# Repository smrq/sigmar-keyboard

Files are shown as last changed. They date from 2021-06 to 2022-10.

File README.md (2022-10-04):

# Sigmar Keyboard

40% split keyboard design



## PCB

The design for the PCB was done in KiCad. The PCB is designed according to the specifications of manufacturing with [JLCPCB](https://jlcpcb.com/).

## Firmware

Prerequisites:

* Podman
* dfu-programmer

Building:

* `make docker` to build the container image
* `make` to build the bootloader and firmware hex files

Flashing:

* `make flash left` or `make flash right`

### Building and flashing in WSL

* Install Ubuntu >= 22.04
* Install usbipd-win
* `sudo apt install dfu-programmer podman`

Flashing:

* In Powershell
	- `usbipd list`
		- Find the entry that corresponds with the keyboard (when in keyboard mode, VID/PID is f055:5164)
	- Press the reset button to switch to flashing mode
		- You will need another keyboard or the on-screen virtual keyboard from now on! If the latter, it might help to type the following commands beforehand, so you only need to press enter.
	- `usbipd wsl attach --busid=#-##`

* In WSL
	- `make flash-left` or `make flash-right`

### Flashing the bootloader with Arduino ISP

* Connect Arduino ISP
	* MOSI Pin 11 (programmer) -> B2 (target)
	* MISO Pin 12 -> B3
	* SCK Pin 13 -> B1
	* RST Pin 10 -> RST
* `make build/sigmar_[osx|windows]_bootloader.hex`
* `avrdude -p atmega32u4 -F -P COM4 -c stk500v1 -b 19200 -U flash:w:build/sigmar_[osx|windows]_bootloader.hex`
	* `-P COM4` should match the serial port for the Arduino ISP

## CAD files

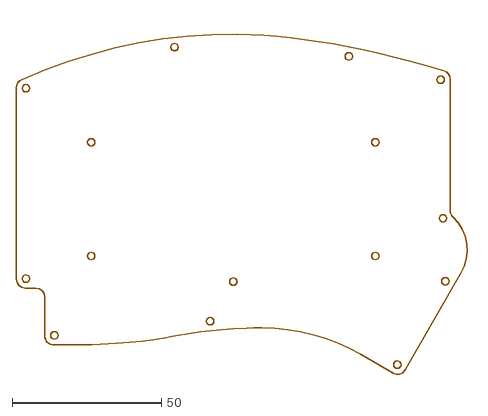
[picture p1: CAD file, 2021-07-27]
model/svg/01-back.dxf
152.5 x 120.4

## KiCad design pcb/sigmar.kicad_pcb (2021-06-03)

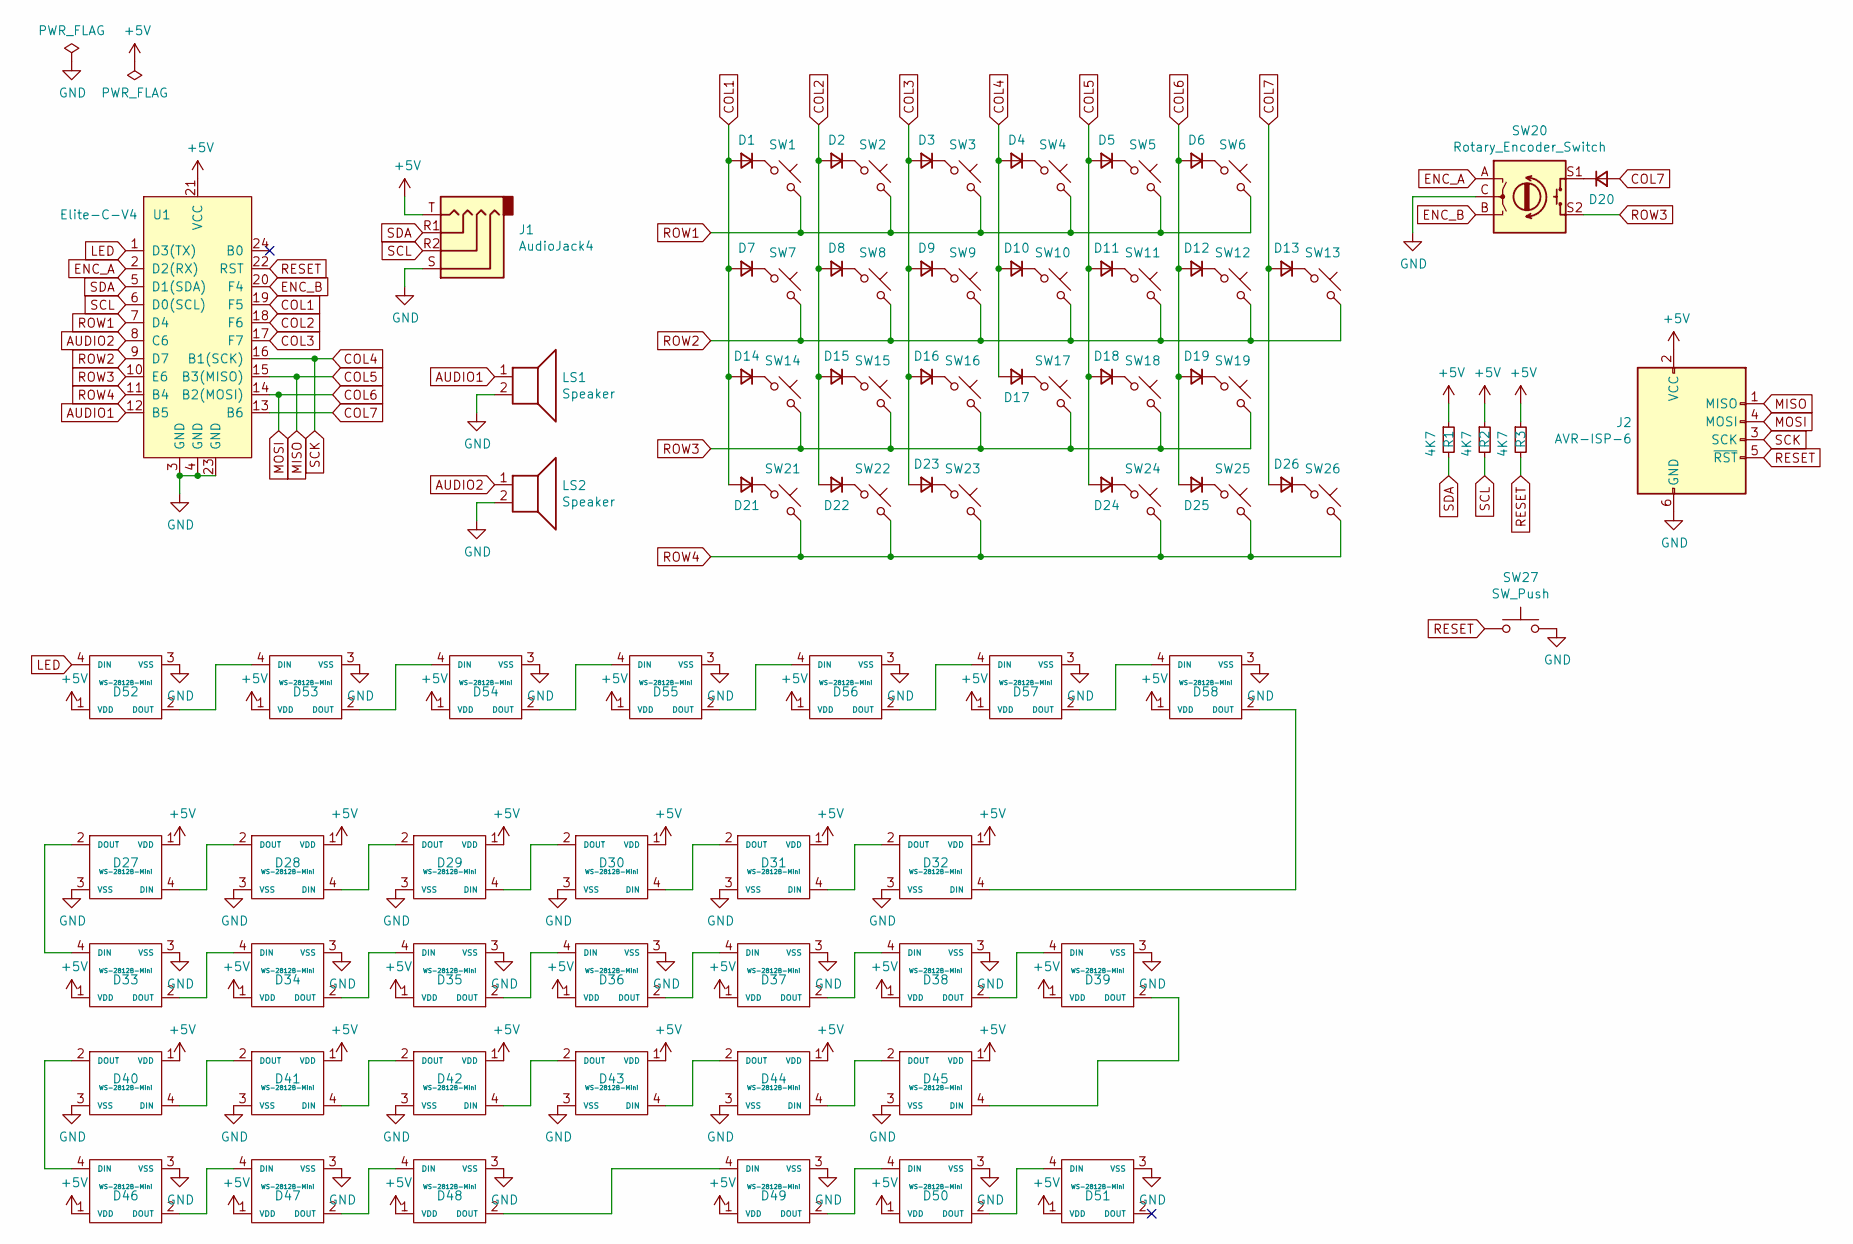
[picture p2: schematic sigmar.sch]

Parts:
D1, D2, D3, D4, D5, D6, D7, D8, D9, D10, D11, D12, D13, D14, D15, D16, D17, D18, D19, D20, D21, D22, D23, D24, D25, D26: D_Small; D_MiniMELF
D27, D28, D29, D30, D31, D32, D33, D34, D35, D36, D37, D38, D39, D40, D41, D42, D43, D44, D45, D46, D47, D48, D49, D50, D51: WS-2812B-Mini; LED_3535_Through_Reversible
D52, D53, D54, D55, D56, D57, D58: WS-2812B-Mini; LED_3535_Reversible
J1: AudioJack4; TRRS-PJ-320A_Reversible
J2: AVR-ISP-6; AVR-ISP
LS1, LS2: Speaker; KLJ-1102_Reversible
R1, R2, R3: 4K7; R_0805
SW1, SW2, SW3, SW4, SW5, SW6, SW7, SW8, SW9, SW10, SW11, SW12, SW14, SW15, SW16, SW17, SW18, SW19, SW21, SW22, SW23, SW24, SW25, SW26: SW_Push_45deg; Cherry_MX_1U_Reversible
SW13: SW_Push_45deg; Cherry_MX_2U_Vert_Reversible
SW20: Rotary_Encoder_Switch; RotaryEncoder_EC11_Reversible
SW27: SW_Push; SPST_MJTP1117_Reversible
U1: Elite-C-V4; Elite-C

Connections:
+5V: D27.1 (VDD), D28.1 (VDD), D29.1 (VDD), D30.1 (VDD), D31.1 (VDD), D32.1 (VDD), D33.1 (VDD), D34.1 (VDD), D35.1 (VDD), D36.1 (VDD), D37.1 (VDD), D38.1 (VDD), D39.1 (VDD), D40.1 (VDD), D41.1 (VDD), D42.1 (VDD), D43.1 (VDD), D44.1 (VDD), D45.1 (VDD), D46.1 (VDD), D47.1 (VDD), D48.1 (VDD), D49.1 (VDD), D50.1 (VDD), D51.1 (VDD), D52.1 (VDD), D53.1 (VDD), D54.1 (VDD), D55.1 (VDD), D56.1 (VDD), D57.1 (VDD), D58.1 (VDD), J1.T, J2.2 (VCC), R1.1, R2.1, R3.1, U1.21 (VCC)
AUDIO1: LS1.1, U1.12 (B5)
AUDIO2: LS2.1, U1.8 (C6)
COL1: D1.2 (A), D7.2 (A), D14.2 (A), D21.2 (A), U1.19 (F5)
COL2: D2.2 (A), D8.2 (A), D15.2 (A), D22.2 (A), U1.18 (F6)
COL3: D3.2 (A), D9.2 (A), D16.2 (A), D23.2 (A), U1.17 (F7)
COL4: D4.2 (A), D10.2 (A), D17.2 (A), J2.3 (SCK), U1.16 (B1(SCK))
COL5: D5.2 (A), D11.2 (A), D18.2 (A), D24.2 (A), J2.1 (MISO), U1.15 (B3(MISO))
COL6: D6.2 (A), D12.2 (A), D19.2 (A), D25.2 (A), J2.4 (MOSI), U1.14 (B2(MOSI))
COL7: D13.2 (A), D20.2 (A), D26.2 (A), U1.13 (B6)
ENC_A: SW20.A, U1.2 (D2(RX))
ENC_B: SW20.B, U1.20 (F4)
GND: D27.3 (VSS), D28.3 (VSS), D29.3 (VSS), D30.3 (VSS), D31.3 (VSS), D32.3 (VSS), D33.3 (VSS), D34.3 (VSS), D35.3 (VSS), D36.3 (VSS), D37.3 (VSS), D38.3 (VSS), D39.3 (VSS), D40.3 (VSS), D41.3 (VSS), D42.3 (VSS), D43.3 (VSS), D44.3 (VSS), D45.3 (VSS), D46.3 (VSS), D47.3 (VSS), D48.3 (VSS), D49.3 (VSS), D50.3 (VSS), D51.3 (VSS), D52.3 (VSS), D53.3 (VSS), D54.3 (VSS), D55.3 (VSS), D56.3 (VSS), D57.3 (VSS), D58.3 (VSS), J1.S, J2.6 (GND), LS1.2, LS2.2, SW20.C, SW27.2, U1.3 (GND), U1.4 (GND), U1.23 (GND)
LED: D52.4 (DIN), U1.1 (D3(TX))
unnamed: D1.1 (K), SW1.1
unnamed: D2.1 (K), SW2.1
unnamed: D3.1 (K), SW3.1
unnamed: D4.1 (K), SW4.1
unnamed: D5.1 (K), SW5.1
unnamed: D6.1 (K), SW6.1
unnamed: D7.1 (K), SW7.1
unnamed: D8.1 (K), SW8.1
unnamed: D9.1 (K), SW9.1
unnamed: D10.1 (K), SW10.1
unnamed: D11.1 (K), SW11.1
unnamed: D12.1 (K), SW12.1
unnamed: D13.1 (K), SW13.1
unnamed: D14.1 (K), SW14.1
unnamed: D15.1 (K), SW15.1
unnamed: D16.1 (K), SW16.1
unnamed: D17.1 (K), SW17.1
unnamed: D18.1 (K), SW18.1
unnamed: D19.1 (K), SW19.1
unnamed: D20.1 (K), SW20.S1
unnamed: D21.1 (K), SW21.1
unnamed: D22.1 (K), SW22.1
unnamed: D23.1 (K), SW23.1
unnamed: D24.1 (K), SW24.1
unnamed: D25.1 (K), SW25.1
unnamed: D26.1 (K), SW26.1
unnamed: D27.2 (DOUT), D33.4 (DIN)
unnamed: D27.4 (DIN), D28.2 (DOUT)
unnamed: D28.4 (DIN), D29.2 (DOUT)
unnamed: D29.4 (DIN), D30.2 (DOUT)
unnamed: D30.4 (DIN), D31.2 (DOUT)
unnamed: D31.4 (DIN), D32.2 (DOUT)
unnamed: D32.4 (DIN), D58.2 (DOUT)
unnamed: D33.2 (DOUT), D34.4 (DIN)
unnamed: D34.2 (DOUT), D35.4 (DIN)
unnamed: D35.2 (DOUT), D36.4 (DIN)
unnamed: D36.2 (DOUT), D37.4 (DIN)
unnamed: D37.2 (DOUT), D38.4 (DIN)
unnamed: D38.2 (DOUT), D39.4 (DIN)
unnamed: D39.2 (DOUT), D45.4 (DIN)
unnamed: D40.2 (DOUT), D46.4 (DIN)
unnamed: D40.4 (DIN), D41.2 (DOUT)
unnamed: D41.4 (DIN), D42.2 (DOUT)
unnamed: D42.4 (DIN), D43.2 (DOUT)
unnamed: D43.4 (DIN), D44.2 (DOUT)
unnamed: D44.4 (DIN), D45.2 (DOUT)
unnamed: D46.2 (DOUT), D47.4 (DIN)
unnamed: D47.2 (DOUT), D48.4 (DIN)
unnamed: D48.2 (DOUT), D49.4 (DIN)
unnamed: D49.2 (DOUT), D50.4 (DIN)
unnamed: D50.2 (DOUT), D51.4 (DIN)
unnamed: D52.2 (DOUT), D53.4 (DIN)
unnamed: D53.2 (DOUT), D54.4 (DIN)
unnamed: D54.2 (DOUT), D55.4 (DIN)
unnamed: D55.2 (DOUT), D56.4 (DIN)
unnamed: D56.2 (DOUT), D57.4 (DIN)
unnamed: D57.2 (DOUT), D58.4 (DIN)
RESET: J2.5 (~RST), R3.2, SW27.1, U1.22 (RST)
ROW1: SW1.2, SW2.2, SW3.2, SW4.2, SW5.2, SW6.2, U1.7 (D4)
ROW2: SW7.2, SW8.2, SW9.2, SW10.2, SW11.2, SW12.2, SW13.2, U1.9 (D7)
ROW3: SW14.2, SW15.2, SW16.2, SW17.2, SW18.2, SW19.2, SW20.S2, U1.10 (E6)
ROW4: SW21.2, SW22.2, SW23.2, SW24.2, SW25.2, SW26.2, U1.11 (B4)
SCL: J1.R2, R2.2, U1.6 (D0(SCL))
SDA: J1.R1, R1.2, U1.5 (D1(SDA))

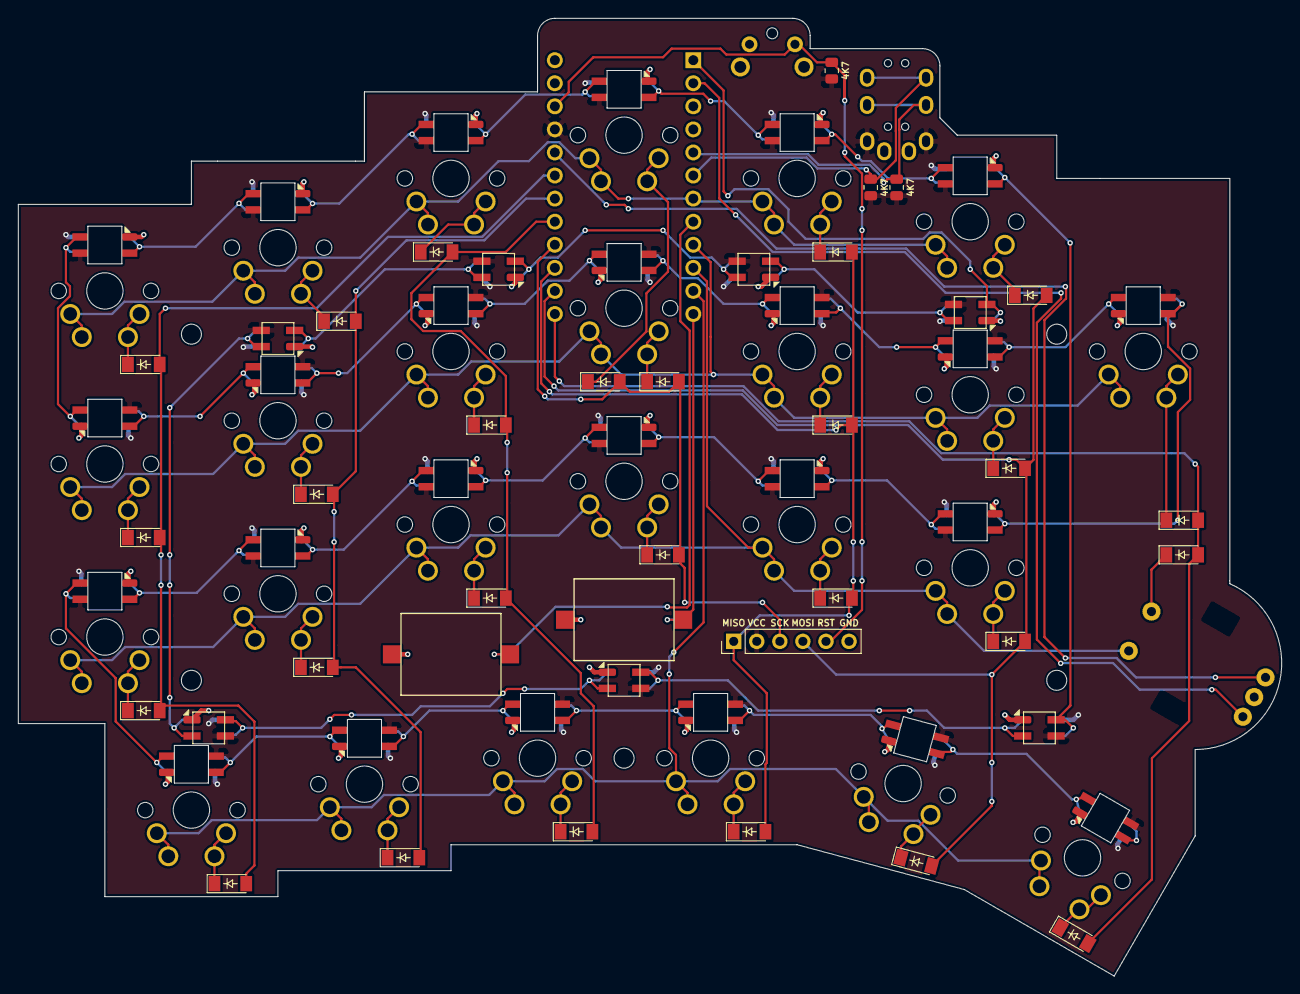
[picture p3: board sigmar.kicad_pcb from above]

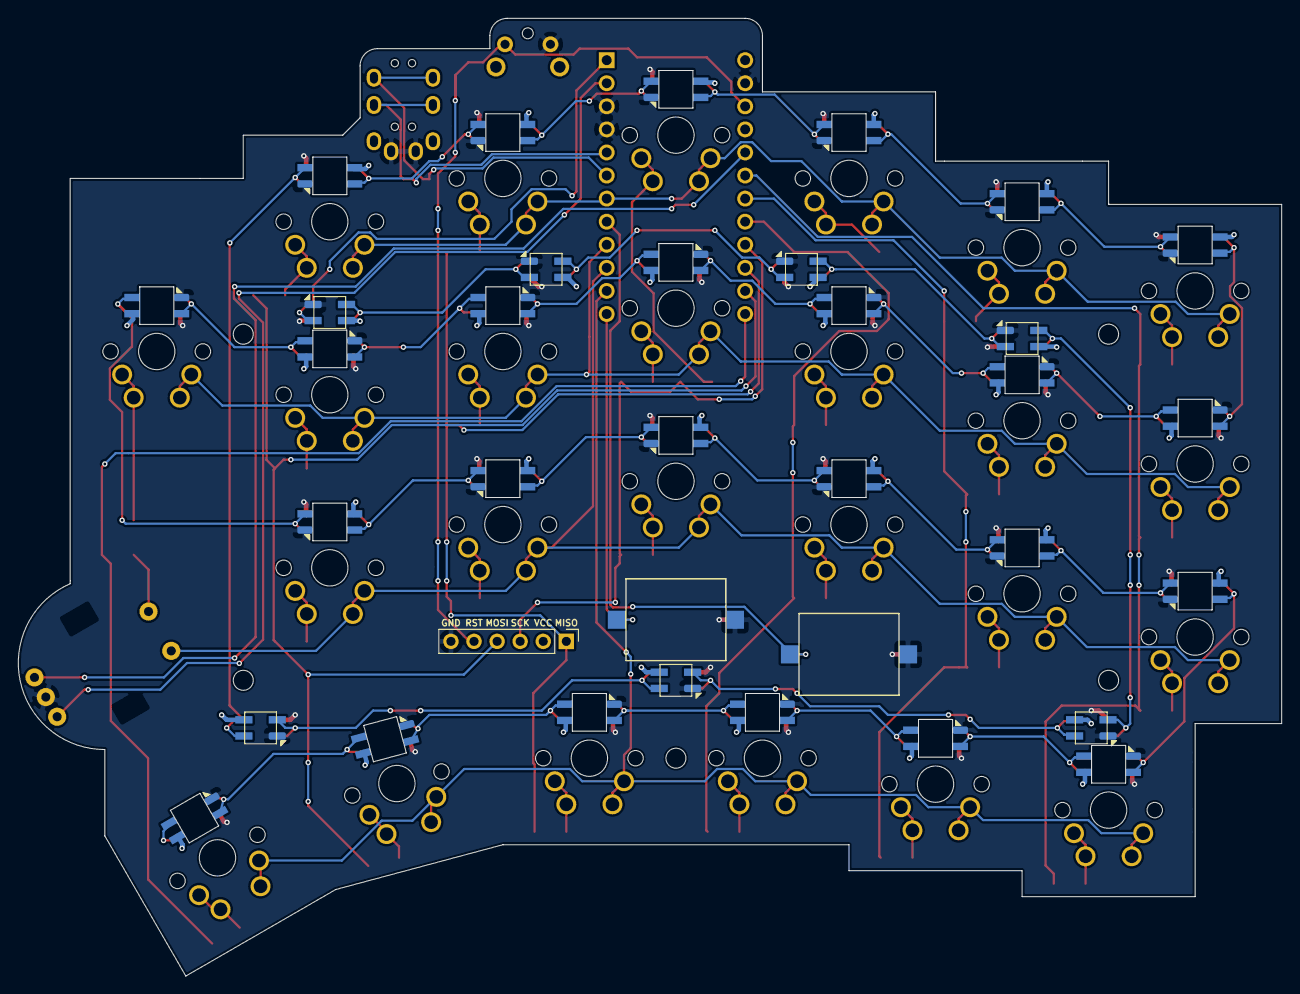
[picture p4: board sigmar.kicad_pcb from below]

Board: 2 copper layers, 139.1 x 105.4 mm, 93 parts (37 on the bottom side), 78 nets.

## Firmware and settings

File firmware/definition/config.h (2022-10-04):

#pragma once

#include "config_common.h"

// https://docs.qmk.fm/#/config_options?id=hardware-options
#define VENDOR_ID    0xF055
#define PRODUCT_ID   0x5164
#define DEVICE_VER   0x0002
#define MANUFACTURER smrq
#define PRODUCT      Sigmar Keyboard

#define MATRIX_ROWS 8
#define MATRIX_COLS 7
#define MATRIX_ROW_PINS { D4, D7, E6, B4 }
#define MATRIX_COL_PINS { F5, F6, F7, B1, B3, B2, B6 }
#define DIODE_DIRECTION COL2ROW

#define DEBOUNCE 5
#define LOCKING_SUPPORT_ENABLE
#define LOCKING_RESYNC_ENABLE

// https://docs.qmk.fm/#/feature_rgb_matrix?id=rgb-matrix-lighting

#ifdef RGB_MATRIX_ENABLE
	#define RGB_DI_PIN D3
	#define DRIVER_LED_TOTAL 64

	#define RGB_MATRIX_SPLIT { 32, 32 }
	// #define RGB_MATRIX_FRAMEBUFFER_EFFECTS
	#define RGB_MATRIX_KEYPRESSES
	#define RGB_MATRIX_MAXIMUM_BRIGHTNESS 120

	#define DISABLE_RGB_MATRIX_ALPHAS_MODS
	#define DISABLE_RGB_MATRIX_GRADIENT_UP_DOWN
	#define DISABLE_RGB_MATRIX_GRADIENT_LEFT_RIGHT
	#define DISABLE_RGB_MATRIX_BREATHING
	#define DISABLE_RGB_MATRIX_BAND_SAT
	#define DISABLE_RGB_MATRIX_BAND_VAL
	#define DISABLE_RGB_MATRIX_BAND_PINWHEEL_SAT
	#define DISABLE_RGB_MATRIX_BAND_PINWHEEL_VAL
	#define DISABLE_RGB_MATRIX_BAND_SPIRAL_SAT
	#define DISABLE_RGB_MATRIX_BAND_SPIRAL_VAL
	#define DISABLE_RGB_MATRIX_CYCLE_ALL
	#define DISABLE_RGB_MATRIX_CYCLE_LEFT_RIGHT
	#define DISABLE_RGB_MATRIX_CYCLE_UP_DOWN
	// #define DISABLE_RGB_MATRIX_RAINBOW_MOVING_CHEVRON
	#define DISABLE_RGB_MATRIX_CYCLE_OUT_IN
	#define DISABLE_RGB_MATRIX_CYCLE_OUT_IN_DUAL
	#define DISABLE_RGB_MATRIX_CYCLE_PINWHEEL
	#define DISABLE_RGB_MATRIX_CYCLE_SPIRAL
	#define DISABLE_RGB_MATRIX_DUAL_BEACON
	#define DISABLE_RGB_MATRIX_RAINBOW_BEACON
	#define DISABLE_RGB_MATRIX_RAINBOW_PINWHEELS
	#define DISABLE_RGB_MATRIX_RAINDROPS
	#define DISABLE_RGB_MATRIX_JELLYBEAN_RAINDROPS
	#define DISABLE_RGB_MATRIX_HUE_BREATHING
	#define DISABLE_RGB_MATRIX_HUE_PENDULUM
	// #define DISABLE_RGB_MATRIX_HUE_WAVE
	#define DISABLE_RGB_MATRIX_TYPING_HEATMAP
	#define DISABLE_RGB_MATRIX_DIGITAL_RAIN
	#define DISABLE_RGB_MATRIX_SOLID_REACTIVE_SIMPLE
	#define DISABLE_RGB_MATRIX_SOLID_REACTIVE
	#define DISABLE_RGB_MATRIX_SOLID_REACTIVE_WIDE
	// #define DISABLE_RGB_MATRIX_SOLID_REACTIVE_MULTIWIDE
	#define DISABLE_RGB_MATRIX_SOLID_REACTIVE_CROSS
	#define DISABLE_RGB_MATRIX_SOLID_REACTIVE_MULTICROSS
	#define DISABLE_RGB_MATRIX_SOLID_REACTIVE_NEXUS
	#define DISABLE_RGB_MATRIX_SOLID_REACTIVE_MULTINEXUS
	#define DISABLE_RGB_MATRIX_SPLASH
	// #define DISABLE_RGB_MATRIX_MULTISPLASH
	#define DISABLE_RGB_MATRIX_SOLID_SPLASH
	// #define DISABLE_RGB_MATRIX_SOLID_MULTISPLASH
#endif

// https://docs.qmk.fm/#/feature_audio?id=audio
#ifdef AUDIO_ENABLE
	#define SND_ONE_UP_SOUND \
	    Q__NOTE(_E6),    \
	    Q__NOTE(_G6),    \
	    Q__NOTE(_E7),    \
	    Q__NOTE(_C7),    \
	    Q__NOTE(_D7),    \
	    Q__NOTE(_G7),

	#define SND_ZELDA_PUZZLE \
	    Q__NOTE(_G5),    \
	    Q__NOTE(_FS5),   \
	    Q__NOTE(_DS5),   \
	    Q__NOTE(_A4),    \
	    Q__NOTE(_GS4),   \
	    Q__NOTE(_E5),    \
	    Q__NOTE(_GS5),   \
	    HD_NOTE(_C6),

	#define SND_MARIO_MUSHROOM \
	    S__NOTE(_C5 ), \
	    S__NOTE(_G4 ), \
	    S__NOTE(_C5 ), \
	    S__NOTE(_E5 ), \
	    S__NOTE(_G5 ), \
	    S__NOTE(_C6 ), \
	    S__NOTE(_G5 ), \
	    S__NOTE(_GS4), \
	    S__NOTE(_C5 ), \
	    S__NOTE(_DS5), \
	    S__NOTE(_GS5), \
	    S__NOTE(_DS5), \
	    S__NOTE(_GS5), \
	    S__NOTE(_C6 ), \
	    S__NOTE(_DS6), \
	    S__NOTE(_GS6), \
	    S__NOTE(_DS6), \
	    S__NOTE(_AS4), \
	    S__NOTE(_D5 ), \
	    S__NOTE(_F5 ), \
	    S__NOTE(_AS5), \
	    S__NOTE(_D6 ), \
	    S__NOTE(_F6 ), \
	    S__NOTE(_AS6), \
	    S__NOTE(_F6 )

	#define SND_RICK_ROLL      \
	    Q__NOTE(_F4),      \
	    Q__NOTE(_G4),      \
	    Q__NOTE(_BF4),     \
	    Q__NOTE(_G4),      \
	    HD_NOTE(_D5),      \
	    HD_NOTE(_D5),      \
	    W__NOTE(_C5),      \
	    S__NOTE(_REST),    \
	    Q__NOTE(_F4),      \
	    Q__NOTE(_G4),      \
	    Q__NOTE(_BF4),     \
	    Q__NOTE(_G4),      \
	    HD_NOTE(_C5),      \
	    HD_NOTE(_C5),      \
	    W__NOTE(_BF4),     \
	    S__NOTE(_REST),    \
	    Q__NOTE(_F4),      \
	    Q__NOTE(_G4),      \
	    Q__NOTE(_BF4),     \
	    Q__NOTE(_G4),      \
	    W__NOTE(_BF4),     \
	    H__NOTE(_C5),      \
	    H__NOTE(_A4),      \
	    H__NOTE(_A4),      \
	    H__NOTE(_G4),      \
	    H__NOTE(_F4),      \
	    H__NOTE(_F4),      \
	    W__NOTE(_C5),      \
	    W__NOTE(_BF4),

	#define AUDIO_PIN C6
	#define AUDIO_PIN_ALT B5

	#define UNICODE_SONG_MAC  SONG(TERMINAL_SOUND)
	#define UNICODE_SONG_LNX  SONG(UNICODE_LINUX)
	#define UNICODE_SONG_WIN  SONG(UNICODE_WINDOWS)
	#define UNICODE_SONG_WINC SONG(UNICODE_WINDOWS)

	#define NO_MUSIC_MODE
#endif

// https://docs.qmk.fm/#/feature_split_keyboard?id=split-keyboard
#define EE_HANDS
// #define USE_I2C
#define USE_SERIAL
#define SOFT_SERIAL_PIN D0
#define SPLIT_TRANSPORT_MIRROR
#define SPLIT_USB_DETECT

// https://docs.qmk.fm/#/feature_encoders?id=encoders
#define ENCODERS_PAD_A { D2 }
#define ENCODERS_PAD_B { F4 }
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

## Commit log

2021-05-23 pcb wip
    [sigmar.kicad_pcb, sigmar.sch]
2021-05-23 Squashed 'pcb/Type-C.pretty/' content from commit fecd1a97d
    git-subtree-dir: pcb/Type-C.pretty
    git-subtree-split: fecd1a97dee885e7daf32da80dfa47e726d59529
    [HRO TYPE-C-31-M-12.step]
2021-05-23 pcb design nearly finalized
    [matrix.sch, sigmar.kicad_pcb, sigmar.sch]
2021-05-23 pcb updates
    [sigmar.kicad_pcb, sigmar.sch]
2021-05-23 pcb left v1.2
    [matrix.sch, sigmar.kicad_pcb, sigmar.sch]
2021-05-24 3d models
    [sigmar.kicad_pcb]
2021-05-24 fine tuning traces
    [sigmar.kicad_pcb]
2021-05-24 pcb fixes
    [components.sch, matrix.sch, sigmar.kicad_pcb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]
2021-05-24 rename schematic and pcb
    [sigmar-left.kicad_pcb, sigmar-left.sch]
2021-05-25 right hand pcb
    [sigmar-right.kicad_pcb, sigmar-right.sch]
2021-05-25 pcb v1.2 final
    [sigmar-left.kicad_pcb, sigmar-right.kicad_pcb]
2021-05-25 make room for stabilizers
    [sigmar-left.kicad_pcb, sigmar-right.kicad_pcb]
2021-05-27 Squashed 'pcb/Keebio-Parts.pretty/' content from commit c7ae3b446
    git-subtree-dir: pcb/Keebio-Parts.pretty
    git-subtree-split: c7ae3b44674679f4d767767c002fed1eacd414a1
    [CUI_SJ-43614-SMT-TR.step, HRO TYPE-C-31-M-12.step, PJ-320A.step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]
2021-06-02 case design
2021-06-02 pcb v1.3
    [components.sch, matrix.sch, sigmar-left.kicad_pcb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]
2021-06-03 pcb v1.3 final
    [sigmar.kicad_pcb]
2021-06-07 case updates
2021-06-10 case v1.3 final
2021-06-10 case v1.3 svg
2021-07-13 Fix screw holes in keyplate
2021-07-27 Increase screw hole size for back plate
    [01-back.dxf]
2022-10-04 Update keymap and fix build
    [config.h]
